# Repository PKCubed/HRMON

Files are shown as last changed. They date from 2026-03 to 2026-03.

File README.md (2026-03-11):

# HRMON
A Stethoscope-shaped Heart Rate Monitor Badge<br>
Created for WWU ENGR355 Winter 2026<br>
Based on the NXP Kinetis KL25 MCU



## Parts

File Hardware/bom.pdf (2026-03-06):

bom

Id Designator | Footprint | Quantity
1 C3,C1,C12,C13 | C_0805_2012Metric_Pad1.18x1.45mm_HandSolder | 4
2 C14,C4,C5,C10,C15,C9,C7,C8 C_0805_2012Metric_Pad1.18x1.45mm_HandSolder | 8
3 J3 | PinHeader_1x08_P2.54mm_Vertical | 1
4 D1,D2,D3 | LED_1206_3216Metric_Pad1.42x1.75mm_HandSolder | 3
5 J9 | PinHeader_1x04_P2.54mm_Vertical | 1
6 D5,D7,D6,D8,D9,D4 | LED_RGB_5050-6 | 6
7 R2,R1,R3 | C_0805_2012Metric_Pad1.18x1.45mm_HandSolder | 3
8 S1,S2,S5,S3,S4 | SW_B3F-1000 | 5
9 R13,R12 | C_0805_2012Metric_Pad1.18x1.45mm_HandSolder | 2
10 R5,R4 | C_0805_2012Metric_Pad1.18x1.45mm_HandSolder | 2
11 C2,C6 | C_0805_2012Metric_Pad1.18x1.45mm_HandSolder | 2
12 U4 | SOIJ8-M_MC_MCH | 1
13 R8,R7 | C_0805_2012Metric_Pad1.18x1.45mm_HandSolder | 2
14 R6 | C_0805_2012Metric_Pad1.18x1.45mm_HandSolder | 1
15 R11,R10 | C_0805_2012Metric_Pad1.18x1.45mm_HandSolder | 2
16 FB1 | L_0603_1608Metric_Pad1.05x0.95mm_HandSolder | 1
17 J1 | PinHeader_2x08_P2.54mm_Vertical | 1
18 R9 | C_0805_2012Metric_Pad1.18x1.45mm_HandSolder | 1
19 J8,J7,J5 | PinHeader_1x02_P2.54mm_Vertical | 3
20 J2 | PinHeader_1x16_P2.54mm_Vertical | 1
21 J4 | PinSocket_2x05_P1.27mm_Vertical | 1
22 SW1 | 09.03290_EAO | 1
23 Q1 | SOT-23_Handsoldering | 1
24 C11 | C_0805_2012Metric_Pad1.18x1.45mm_HandSolder | 1
25 Y1 | XTAL_ABM3-8.000MHZ-D2Y-T | 1
26 U1 | LQFP-80_12x12mm_P0.5mm | 1
27 U5 | DBV5 | 1
28 J6 | PinHeader_2x02_P2.54mm_Vertical | 1
29 U3 | TO-92_Inline | 1

bom

Designation | Supplier and ref Have already?
10uF
0.1uF
Conn_01x08_Pin
LED
Conn_01x04_Pin
APA102
220
B3F-1000
10k
510
1uF
25LC1024-I/SM
4.7k
1k
2Meg
FerriteBead
8x2 Character LCD
1000R
Conn_01x02_Pin
Conn_01x16_Pin
Conn_02x05_Odd_Even
09.03290.01
NPN
1u
ABM3-8.000MHZ-D2Y-T
MKL25Z128VLK4
OPA377AIDBVR
Conn_02x02_Odd_Even
MCP1700x-330xxTO

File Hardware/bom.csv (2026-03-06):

Id | Designator | Footprint | Quantity | Designation | Supplier and ref
1 | C3,C1,C12,C13 | C_0805_2012Metric_Pad1.18x1.45mm_HandSolder | 4 | 10uF
2 | C14,C4,C5,C10,C15,C9,C7,C8 | C_0805_2012Metric_Pad1.18x1.45mm_HandSolder | 8 | 0.1uF
3 | J3 | PinHeader_1x08_P2.54mm_Vertical | 1 | Conn_01x08_Pin
4 | D1,D2,D3 | LED_1206_3216Metric_Pad1.42x1.75mm_HandSolder | 3 | LED
5 | J9 | PinHeader_1x04_P2.54mm_Vertical | 1 | Conn_01x04_Pin
6 | D5,D7,D6,D8,D9,D4 | LED_RGB_5050-6 | 6 | APA102
7 | R2,R1,R3 | C_0805_2012Metric_Pad1.18x1.45mm_HandSolder | 3 | 220
8 | S1,S2,S5,S3,S4 | SW_B3F-1000 | 5 | B3F-1000
9 | R13,R12 | C_0805_2012Metric_Pad1.18x1.45mm_HandSolder | 2 | 10k
10 | R5,R4 | C_0805_2012Metric_Pad1.18x1.45mm_HandSolder | 2 | 510
11 | C2,C6 | C_0805_2012Metric_Pad1.18x1.45mm_HandSolder | 2 | 1uF
12 | U4 | SOIJ8-M_MC_MCH | 1 | 25LC1024-I/SM
13 | R8,R7 | C_0805_2012Metric_Pad1.18x1.45mm_HandSolder | 2 | 4.7k
14 | R6 | C_0805_2012Metric_Pad1.18x1.45mm_HandSolder | 1 | 1k
15 | R11,R10 | C_0805_2012Metric_Pad1.18x1.45mm_HandSolder | 2 | 2Meg
16 | FB1 | L_0603_1608Metric_Pad1.05x0.95mm_HandSolder | 1 | FerriteBead
17 | J1 | PinHeader_2x08_P2.54mm_Vertical | 1 | 8x2 Character LCD
18 | R9 | C_0805_2012Metric_Pad1.18x1.45mm_HandSolder | 1 | 1000R
19 | J8,J7,J5 | PinHeader_1x02_P2.54mm_Vertical | 3 | Conn_01x02_Pin
20 | J2 | PinHeader_1x16_P2.54mm_Vertical | 1 | Conn_01x16_Pin
21 | J4 | PinSocket_2x05_P1.27mm_Vertical | 1 | Conn_02x05_Odd_Even
22 | SW1 | 09.03290_EAO | 1 | 09.03290.01
23 | Q1 | SOT-23_Handsoldering | 1 | NPN
24 | C11 | C_0805_2012Metric_Pad1.18x1.45mm_HandSolder | 1 | 1u
25 | Y1 | XTAL_ABM3-8.000MHZ-D2Y-T | 1 | ABM3-8.000MHZ-D2Y-T
26 | U1 | LQFP-80_12x12mm_P0.5mm | 1 | MKL25Z128VLK4
27 | U5 | DBV5 | 1 | OPA377AIDBVR
28 | J6 | PinHeader_2x02_P2.54mm_Vertical | 1 | Conn_02x02_Odd_Even
29 | U3 | TO-92_Inline | 1 | MCP1700x-330xxTO

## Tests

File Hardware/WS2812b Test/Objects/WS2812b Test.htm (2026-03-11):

# Static Call Graph for image .\Objects\WS2812b Test.axf

#<CALLGRAPH># ARM Linker, 6240002: Last Updated: Sun Jan 18 12:48:08 2026

### Maximum Stack Usage = 68 bytes + Unknown(Functions without stacksize, Cycles, Untraceable Function Pointers)

### Call chain for Maximum Stack Depth:

__rt_entry_main ⇒ main ⇒ Send_Pixel

### Functions with no stack information

- __user_initial_stackheap

### Mutually Recursive functions

- NMI_Handler ⇒ NMI_Handler
- HardFault_Handler ⇒ HardFault_Handler
- SVC_Handler ⇒ SVC_Handler
- PendSV_Handler ⇒ PendSV_Handler
- SysTick_Handler ⇒ SysTick_Handler

### Function Pointers

- ADC0_IRQHandler from startup_mkl25z4.o(.text) referenced from startup_mkl25z4.o(RESET)
- CMP0_IRQHandler from startup_mkl25z4.o(.text) referenced from startup_mkl25z4.o(RESET)
- DAC0_IRQHandler from startup_mkl25z4.o(.text) referenced from startup_mkl25z4.o(RESET)
- DMA0_IRQHandler from startup_mkl25z4.o(.text) referenced from startup_mkl25z4.o(RESET)
- DMA1_IRQHandler from startup_mkl25z4.o(.text) referenced from startup_mkl25z4.o(RESET)
- DMA2_IRQHandler from startup_mkl25z4.o(.text) referenced from startup_mkl25z4.o(RESET)
- DMA3_IRQHandler from startup_mkl25z4.o(.text) referenced from startup_mkl25z4.o(RESET)
- DefaultISR from startup_mkl25z4.o(.text) referenced from startup_mkl25z4.o(.text)
- FTFA_IRQHandler from startup_mkl25z4.o(.text) referenced from startup_mkl25z4.o(RESET)
- HardFault_Handler from startup_mkl25z4.o(.text) referenced from startup_mkl25z4.o(RESET)
- I2C0_IRQHandler from startup_mkl25z4.o(.text) referenced from startup_mkl25z4.o(RESET)
- I2C1_IRQHandler from startup_mkl25z4.o(.text) referenced from startup_mkl25z4.o(RESET)
- LLWU_IRQHandler from startup_mkl25z4.o(.text) referenced from startup_mkl25z4.o(RESET)
- LPTMR0_IRQHandler from startup_mkl25z4.o(.text) referenced from startup_mkl25z4.o(RESET)
- LVD_LVW_IRQHandler from startup_mkl25z4.o(.text) referenced from startup_mkl25z4.o(RESET)
- MCG_IRQHandler from startup_mkl25z4.o(.text) referenced from startup_mkl25z4.o(RESET)
- NMI_Handler from startup_mkl25z4.o(.text) referenced from startup_mkl25z4.o(RESET)
- PIT_IRQHandler from startup_mkl25z4.o(.text) referenced from startup_mkl25z4.o(RESET)
- PORTA_IRQHandler from startup_mkl25z4.o(.text) referenced from startup_mkl25z4.o(RESET)
- PORTD_IRQHandler from startup_mkl25z4.o(.text) referenced from startup_mkl25z4.o(RESET)
- PendSV_Handler from startup_mkl25z4.o(.text) referenced from startup_mkl25z4.o(RESET)
- RTC_IRQHandler from startup_mkl25z4.o(.text) referenced from startup_mkl25z4.o(RESET)
- RTC_Seconds_IRQHandler from startup_mkl25z4.o(.text) referenced from startup_mkl25z4.o(RESET)
- Reserved20_IRQHandler from startup_mkl25z4.o(.text) referenced from startup_mkl25z4.o(RESET)
- Reserved39_IRQHandler from startup_mkl25z4.o(.text) referenced from startup_mkl25z4.o(RESET)
- Reserved45_IRQHandler from startup_mkl25z4.o(.text) referenced from startup_mkl25z4.o(RESET)
- Reset_Handler from startup_mkl25z4.o(.text) referenced from startup_mkl25z4.o(RESET)
- SPI0_IRQHandler from startup_mkl25z4.o(.text) referenced from startup_mkl25z4.o(RESET)
- SPI1_IRQHandler from startup_mkl25z4.o(.text) referenced from startup_mkl25z4.o(RESET)
- SVC_Handler from startup_mkl25z4.o(.text) referenced from startup_mkl25z4.o(RESET)
- SysTick_Handler from startup_mkl25z4.o(.text) referenced from startup_mkl25z4.o(RESET)
- SystemInit from system_mkl25z4.o(.text.SystemInit) referenced from startup_mkl25z4.o(.text)
- TPM0_IRQHandler from startup_mkl25z4.o(.text) referenced from startup_mkl25z4.o(RESET)
- TPM1_IRQHandler from startup_mkl25z4.o(.text) referenced from startup_mkl25z4.o(RESET)
- TPM2_IRQHandler from startup_mkl25z4.o(.text) referenced from startup_mkl25z4.o(RESET)
- TSI0_IRQHandler from startup_mkl25z4.o(.text) referenced from startup_mkl25z4.o(RESET)
- UART0_IRQHandler from startup_mkl25z4.o(.text) referenced from startup_mkl25z4.o(RESET)
- UART1_IRQHandler from startup_mkl25z4.o(.text) referenced from startup_mkl25z4.o(RESET)
- UART2_IRQHandler from startup_mkl25z4.o(.text) referenced from startup_mkl25z4.o(RESET)
- USB0_IRQHandler from startup_mkl25z4.o(.text) referenced from startup_mkl25z4.o(RESET)
- __main from __main.o(!!!main) referenced from startup_mkl25z4.o(.text)

### Global Symbols

__main (Thumb, 8 bytes, Stack size 0 bytes, __main.o(!!!main))

[Calls]

- >> __scatterload
- >> __rt_entry

[Address Reference Count : 1]

- startup_mkl25z4.o(.text)

__scatterload (Thumb, 0 bytes, Stack size unknown bytes, __scatter.o(!!!scatter))

[Called By]

- >> __main

__scatterload_rt2 (Thumb, 74 bytes, Stack size unknown bytes, __scatter.o(!!!scatter), UNUSED)

[Calls]

- >> __rt_entry

__scatterload_rt2_thumb_only (Thumb, 0 bytes, Stack size unknown bytes, __scatter.o(!!!scatter), UNUSED)

__scatterload_loop (Thumb, 0 bytes, Stack size unknown bytes, __scatter.o(!!!scatter), UNUSED)

__scatterload_null (Thumb, 2 bytes, Stack size unknown bytes, __scatter.o(!!handler_null), UNUSED)

__scatterload_zeroinit (Thumb, 28 bytes, Stack size unknown bytes, __scatter_zi.o(!!handler_zi), UNUSED)

__rt_lib_init (Thumb, 0 bytes, Stack size unknown bytes, libinit.o(.ARM.Collect$$libinit$$00000000))

[Called By]

- >> __rt_entry_li

__rt_lib_init_alloca_1 (Thumb, 0 bytes, Stack size unknown bytes, libinit2.o(.ARM.Collect$$libinit$$00000030))

__rt_lib_init_argv_1 (Thumb, 0 bytes, Stack size unknown bytes, libinit2.o(.ARM.Collect$$libinit$$0000002E))

__rt_lib_init_atexit_1 (Thumb, 0 bytes, Stack size unknown bytes, libinit2.o(.ARM.Collect$$libinit$$0000001D))

__rt_lib_init_clock_1 (Thumb, 0 bytes, Stack size unknown bytes, libinit2.o(.ARM.Collect$$libinit$$00000023))

__rt_lib_init_cpp_1 (Thumb, 0 bytes, Stack size unknown bytes, libinit2.o(.ARM.Collect$$libinit$$00000034))

__rt_lib_init_exceptions_1 (Thumb, 0 bytes, Stack size unknown bytes, libinit2.o(.ARM.Collect$$libinit$$00000032))

__rt_lib_init_fp_1 (Thumb, 0 bytes, Stack size unknown bytes, libinit2.o(.ARM.Collect$$libinit$$00000002))

__rt_lib_init_fp_trap_1 (Thumb, 0 bytes, Stack size unknown bytes, libinit2.o(.ARM.Collect$$libinit$$00000021))

__rt_lib_init_getenv_1 (Thumb, 0 bytes, Stack size unknown bytes, libinit2.o(.ARM.Collect$$libinit$$00000025))

__rt_lib_init_heap_1 (Thumb, 0 bytes, Stack size unknown bytes, libinit2.o(.ARM.Collect$$libinit$$0000000C))

__rt_lib_init_lc_collate_1 (Thumb, 0 bytes, Stack size unknown bytes, libinit2.o(.ARM.Collect$$libinit$$00000013))

__rt_lib_init_lc_ctype_1 (Thumb, 0 bytes, Stack size unknown bytes, libinit2.o(.ARM.Collect$$libinit$$00000015))

__rt_lib_init_lc_monetary_1 (Thumb, 0 bytes, Stack size unknown bytes, libinit2.o(.ARM.Collect$$libinit$$00000017))

__rt_lib_init_lc_numeric_1 (Thumb, 0 bytes, Stack size unknown bytes, libinit2.o(.ARM.Collect$$libinit$$00000019))

__rt_lib_init_lc_time_1 (Thumb, 0 bytes, Stack size unknown bytes, libinit2.o(.ARM.Collect$$libinit$$0000001B))

__rt_lib_init_preinit_1 (Thumb, 0 bytes, Stack size unknown bytes, libinit2.o(.ARM.Collect$$libinit$$00000006))

__rt_lib_init_rand_1 (Thumb, 0 bytes, Stack size unknown bytes, libinit2.o(.ARM.Collect$$libinit$$00000010))

__rt_lib_init_relocate_pie_1 (Thumb, 0 bytes, Stack size unknown bytes, libinit2.o(.ARM.Collect$$libinit$$00000004))

__rt_lib_init_return (Thumb, 0 bytes, Stack size unknown bytes, libinit2.o(.ARM.Collect$$libinit$$00000035))

__rt_lib_init_signal_1 (Thumb, 0 bytes, Stack size unknown bytes, libinit2.o(.ARM.Collect$$libinit$$0000001F))

__rt_lib_init_stdio_1 (Thumb, 0 bytes, Stack size unknown bytes, libinit2.o(.ARM.Collect$$libinit$$00000027))

__rt_lib_init_user_alloc_1 (Thumb, 0 bytes, Stack size unknown bytes, libinit2.o(.ARM.Collect$$libinit$$0000000E))

__rt_lib_shutdown (Thumb, 0 bytes, Stack size unknown bytes, libshutdown.o(.ARM.Collect$$libshutdown$$00000000))

[Called By]

- >> __rt_exit_ls

__rt_lib_shutdown_cpp_1 (Thumb, 0 bytes, Stack size unknown bytes, libshutdown2.o(.ARM.Collect$$libshutdown$$00000002))

__rt_lib_shutdown_fp_trap_1 (Thumb, 0 bytes, Stack size unknown bytes, libshutdown2.o(.ARM.Collect$$libshutdown$$00000007))

__rt_lib_shutdown_heap_1 (Thumb, 0 bytes, Stack size unknown bytes, libshutdown2.o(.ARM.Collect$$libshutdown$$0000000F))

__rt_lib_shutdown_return (Thumb, 0 bytes, Stack size unknown bytes, libshutdown2.o(.ARM.Collect$$libshutdown$$00000010))

__rt_lib_shutdown_signal_1 (Thumb, 0 bytes, Stack size unknown bytes, libshutdown2.o(.ARM.Collect$$libshutdown$$0000000A))

__rt_lib_shutdown_stdio_1 (Thumb, 0 bytes, Stack size unknown bytes, libshutdown2.o(.ARM.Collect$$libshutdown$$00000004))

__rt_lib_shutdown_user_alloc_1 (Thumb, 0 bytes, Stack size unknown bytes, libshutdown2.o(.ARM.Collect$$libshutdown$$0000000C))

__rt_entry (Thumb, 0 bytes, Stack size unknown bytes, __rtentry.o(.ARM.Collect$$rtentry$$00000000))

[Called By]

- >> __scatterload_rt2
- >> __main

__rt_entry_presh_1 (Thumb, 0 bytes, Stack size unknown bytes, __rtentry2.o(.ARM.Collect$$rtentry$$00000002))

__rt_entry_sh (Thumb, 0 bytes, Stack size unknown bytes, __rtentry4.o(.ARM.Collect$$rtentry$$00000004))

[Stack]

- Max Depth = 8 + Unknown Stack Size
- Call Chain = __rt_entry_sh ⇒ __user_setup_stackheap

[Calls]

- >> __user_setup_stackheap

__rt_entry_li (Thumb, 0 bytes, Stack size unknown bytes, __rtentry2.o(.ARM.Collect$$rtentry$$0000000A))

[Calls]

- >> __rt_lib_init

__rt_entry_postsh_1 (Thumb, 0 bytes, Stack size unknown bytes, __rtentry2.o(.ARM.Collect$$rtentry$$00000009))

__rt_entry_main (Thumb, 0 bytes, Stack size unknown bytes, __rtentry2.o(.ARM.Collect$$rtentry$$0000000D))

[Stack]

- Max Depth = 68 + Unknown Stack Size
- Call Chain = __rt_entry_main ⇒ main ⇒ Send_Pixel

[Calls]

- >> exit
- >> main

__rt_entry_postli_1 (Thumb, 0 bytes, Stack size unknown bytes, __rtentry2.o(.ARM.Collect$$rtentry$$0000000C))

__rt_exit (Thumb, 0 bytes, Stack size unknown bytes, rtexit.o(.ARM.Collect$$rtexit$$00000000))

[Called By]

- >> exit

__rt_exit_ls (Thumb, 0 bytes, Stack size unknown bytes, rtexit2.o(.ARM.Collect$$rtexit$$00000003))

[Calls]

- >> __rt_lib_shutdown

__rt_exit_prels_1 (Thumb, 0 bytes, Stack size unknown bytes, rtexit2.o(.ARM.Collect$$rtexit$$00000002))

__rt_exit_exit (Thumb, 0 bytes, Stack size unknown bytes, rtexit2.o(.ARM.Collect$$rtexit$$00000004))

[Calls]

- >> _sys_exit

Reset_Handler (Thumb, 12 bytes, Stack size 0 bytes, startup_mkl25z4.o(.text))
[Address Reference Count : 1]

- startup_mkl25z4.o(RESET)

NMI_Handler (Thumb, 2 bytes, Stack size 0 bytes, startup_mkl25z4.o(.text))

[Calls]

- >> NMI_Handler

[Called By]

- >> NMI_Handler

[Address Reference Count : 1]

- startup_mkl25z4.o(RESET)

HardFault_Handler (Thumb, 2 bytes, Stack size 0 bytes, startup_mkl25z4.o(.text))

[Calls]

- >> HardFault_Handler

[Called By]

- >> HardFault_Handler

[Address Reference Count : 1]

- startup_mkl25z4.o(RESET)

SVC_Handler (Thumb, 2 bytes, Stack size 0 bytes, startup_mkl25z4.o(.text))

[Calls]

- >> SVC_Handler

[Called By]

- >> SVC_Handler

[Address Reference Count : 1]

- startup_mkl25z4.o(RESET)

PendSV_Handler (Thumb, 2 bytes, Stack size 0 bytes, startup_mkl25z4.o(.text))

[Calls]

- >> PendSV_Handler

[Called By]

- >> PendSV_Handler

[Address Reference Count : 1]

- startup_mkl25z4.o(RESET)

SysTick_Handler (Thumb, 2 bytes, Stack size 0 bytes, startup_mkl25z4.o(.text))

[Calls]

- >> SysTick_Handler

[Called By]

- >> SysTick_Handler

[Address Reference Count : 1]

- startup_mkl25z4.o(RESET)

ADC0_IRQHandler (Thumb, 0 bytes, Stack size 0 bytes, startup_mkl25z4.o(.text))
[Address Reference Count : 1]

- startup_mkl25z4.o(RESET)

CMP0_IRQHandler (Thumb, 0 bytes, Stack size 0 bytes, startup_mkl25z4.o(.text))
[Address Reference Count : 1]

- startup_mkl25z4.o(RESET)

DAC0_IRQHandler (Thumb, 0 bytes, Stack size 0 bytes, startup_mkl25z4.o(.text))
[Address Reference Count : 1]

- startup_mkl25z4.o(RESET)

DMA0_IRQHandler (Thumb, 0 bytes, Stack size 0 bytes, startup_mkl25z4.o(.text))
[Address Reference Count : 1]

- startup_mkl25z4.o(RESET)

DMA1_IRQHandler (Thumb, 0 bytes, Stack size 0 bytes, startup_mkl25z4.o(.text))
[Address Reference Count : 1]

- startup_mkl25z4.o(RESET)

DMA2_IRQHandler (Thumb, 0 bytes, Stack size 0 bytes, startup_mkl25z4.o(.text))
[Address Reference Count : 1]

- startup_mkl25z4.o(RESET)

DMA3_IRQHandler (Thumb, 0 bytes, Stack size 0 bytes, startup_mkl25z4.o(.text))
[Address Reference Count : 1]

- startup_mkl25z4.o(RESET)

DefaultISR (Thumb, 0 bytes, Stack size 0 bytes, startup_mkl25z4.o(.text))
[Address Reference Count : 1]

- startup_mkl25z4.o(.text)

FTFA_IRQHandler (Thumb, 0 bytes, Stack size 0 bytes, startup_mkl25z4.o(.text))
[Address Reference Count : 1]

- startup_mkl25z4.o(RESET)

I2C0_IRQHandler (Thumb, 0 bytes, Stack size 0 bytes, startup_mkl25z4.o(.text))
[Address Reference Count : 1]

- startup_mkl25z4.o(RESET)

I2C1_IRQHandler (Thumb, 0 bytes, Stack size 0 bytes, startup_mkl25z4.o(.text))
[Address Reference Count : 1]

- startup_mkl25z4.o(RESET)

LLWU_IRQHandler (Thumb, 0 bytes, Stack size 0 bytes, startup_mkl25z4.o(.text))
[Address Reference Count : 1]

- startup_mkl25z4.o(RESET)

LPTMR0_IRQHandler (Thumb, 0 bytes, Stack size 0 bytes, startup_mkl25z4.o(.text))
[Address Reference Count : 1]

- startup_mkl25z4.o(RESET)

LVD_LVW_IRQHandler (Thumb, 0 bytes, Stack size 0 bytes, startup_mkl25z4.o(.text))
[Address Reference Count : 1]

- startup_mkl25z4.o(RESET)

MCG_IRQHandler (Thumb, 0 bytes, Stack size 0 bytes, startup_mkl25z4.o(.text))
[Address Reference Count : 1]

- startup_mkl25z4.o(RESET)

PIT_IRQHandler (Thumb, 0 bytes, Stack size 0 bytes, startup_mkl25z4.o(.text))
[Address Reference Count : 1]

- startup_mkl25z4.o(RESET)

PORTA_IRQHandler (Thumb, 0 bytes, Stack size 0 bytes, startup_mkl25z4.o(.text))
[Address Reference Count : 1]

- startup_mkl25z4.o(RESET)

PORTD_IRQHandler (Thumb, 0 bytes, Stack size 0 bytes, startup_mkl25z4.o(.text))
[Address Reference Count : 1]

- startup_mkl25z4.o(RESET)

RTC_IRQHandler (Thumb, 0 bytes, Stack size 0 bytes, startup_mkl25z4.o(.text))
[Address Reference Count : 1]

- startup_mkl25z4.o(RESET)

RTC_Seconds_IRQHandler (Thumb, 0 bytes, Stack size 0 bytes, startup_mkl25z4.o(.text))
[Address Reference Count : 1]

- startup_mkl25z4.o(RESET)

Reserved20_IRQHandler (Thumb, 0 bytes, Stack size 0 bytes, startup_mkl25z4.o(.text))
[Address Reference Count : 1]

- startup_mkl25z4.o(RESET)

Reserved39_IRQHandler (Thumb, 0 bytes, Stack size 0 bytes, startup_mkl25z4.o(.text))
[Address Reference Count : 1]

- startup_mkl25z4.o(RESET)

Reserved45_IRQHandler (Thumb, 0 bytes, Stack size 0 bytes, startup_mkl25z4.o(.text))
[Address Reference Count : 1]

- startup_mkl25z4.o(RESET)

SPI0_IRQHandler (Thumb, 0 bytes, Stack size 0 bytes, startup_mkl25z4.o(.text))
[Address Reference Count : 1]

- startup_mkl25z4.o(RESET)

SPI1_IRQHandler (Thumb, 0 bytes, Stack size 0 bytes, startup_mkl25z4.o(.text))
[Address Reference Count : 1]

- startup_mkl25z4.o(RESET)

TPM0_IRQHandler (Thumb, 0 bytes, Stack size 0 bytes, startup_mkl25z4.o(.text))
[Address Reference Count : 1]

- startup_mkl25z4.o(RESET)

TPM1_IRQHandler (Thumb, 0 bytes, Stack size 0 bytes, startup_mkl25z4.o(.text))
[Address Reference Count : 1]

- startup_mkl25z4.o(RESET)

TPM2_IRQHandler (Thumb, 0 bytes, Stack size 0 bytes, startup_mkl25z4.o(.text))
[Address Reference Count : 1]

- startup_mkl25z4.o(RESET)

TSI0_IRQHandler (Thumb, 0 bytes, Stack size 0 bytes, startup_mkl25z4.o(.text))
[Address Reference Count : 1]

- startup_mkl25z4.o(RESET)

UART0_IRQHandler (Thumb, 0 bytes, Stack size 0 bytes, startup_mkl25z4.o(.text))
[Address Reference Count : 1]

- startup_mkl25z4.o(RESET)

UART1_IRQHandler (Thumb, 0 bytes, Stack size 0 bytes, startup_mkl25z4.o(.text))
[Address Reference Count : 1]

- startup_mkl25z4.o(RESET)

UART2_IRQHandler (Thumb, 0 bytes, Stack size 0 bytes, startup_mkl25z4.o(.text))
[Address Reference Count : 1]

- startup_mkl25z4.o(RESET)

USB0_IRQHandler (Thumb, 0 bytes, Stack size 0 bytes, startup_mkl25z4.o(.text))
[Address Reference Count : 1]

- startup_mkl25z4.o(RESET)

__user_initial_stackheap (Thumb, 0 bytes, Stack size unknown bytes, startup_mkl25z4.o(.text))

[Called By]

- >> __user_setup_stackheap

__use_two_region_memory (Thumb, 2 bytes, Stack size 0 bytes, heapauxi.o(.text), UNUSED)

__rt_heap_escrow$2region (Thumb, 2 bytes, Stack size 0 bytes, heapauxi.o(.text), UNUSED)

__rt_heap_expand$2region (Thumb, 2 bytes, Stack size 0 bytes, heapauxi.o(.text), UNUSED)

__user_setup_stackheap (Thumb, 62 bytes, Stack size 8 bytes, sys_stackheap_outer.o(.text))

[Stack]

- Max Depth = 8 + Unknown Stack Size
- Call Chain = __user_setup_stackheap

[Calls]

- >> __user_perproc_libspace
- >> __user_initial_stackheap

[Called By]

- >> __rt_entry_sh

exit (Thumb, 16 bytes, Stack size 8 bytes, exit.o(.text))

[Stack]

- Max Depth = 8 + Unknown Stack Size
- Call Chain = exit

[Calls]

- >> __rt_exit
- >> _call_atexit_fns (Weak Reference)

[Called By]

- >> __rt_entry_main

__user_libspace (Thumb, 8 bytes, Stack size 0 bytes, libspace.o(.text), UNUSED)

__user_perproc_libspace (Thumb, 0 bytes, Stack size 0 bytes, libspace.o(.text))

[Called By]

- >> __user_setup_stackheap

__user_perthread_libspace (Thumb, 0 bytes, Stack size 0 bytes, libspace.o(.text), UNUSED)

_sys_exit (Thumb, 8 bytes, Stack size 0 bytes, sys_exit.o(.text))

[Called By]

- >> __rt_exit_exit

__I$use$semihosting (Thumb, 0 bytes, Stack size 0 bytes, use_no_semi.o(.text), UNUSED)

__use_no_semihosting_swi (Thumb, 2 bytes, Stack size 0 bytes, use_no_semi.o(.text), UNUSED)

Delay (Thumb, 26 bytes, Stack size 4 bytes, main.o(.text.Delay))

[Stack]

- Max Depth = 4
- Call Chain = Delay

[Called By]

- >> main

__semihosting_library_function (Thumb, 0 bytes, Stack size 4 bytes, indicate_semi.o(.text), UNUSED)

Init_GPIO (Thumb, 36 bytes, Stack size 0 bytes, main.o(.text.Init_GPIO))

[Called By]

- >> main

Send_Pixel (Thumb, 228 bytes, Stack size 44 bytes, main.o(.text.Send_Pixel))

[Stack]

- Max Depth = 44
- Call Chain = Send_Pixel

[Called By]

- >> main

SystemInit (Thumb, 8 bytes, Stack size 0 bytes, system_mkl25z4.o(.text.SystemInit))
[Address Reference Count : 1]

- startup_mkl25z4.o(.text)

main (Thumb, 92 bytes, Stack size 24 bytes, main.o(.text.main))

[Stack]

- Max Depth = 68
- Call Chain = main ⇒ Send_Pixel

[Calls]

- >> Send_Pixel
- >> Init_GPIO
- >> Delay

[Called By]

- >> __rt_entry_main

### Local Symbols

### Undefined Global Symbols

_call_atexit_fns (ARM, 0 bytes, Stack size 0 bytes, UNDEFINED)

[Called By]

- >> exit

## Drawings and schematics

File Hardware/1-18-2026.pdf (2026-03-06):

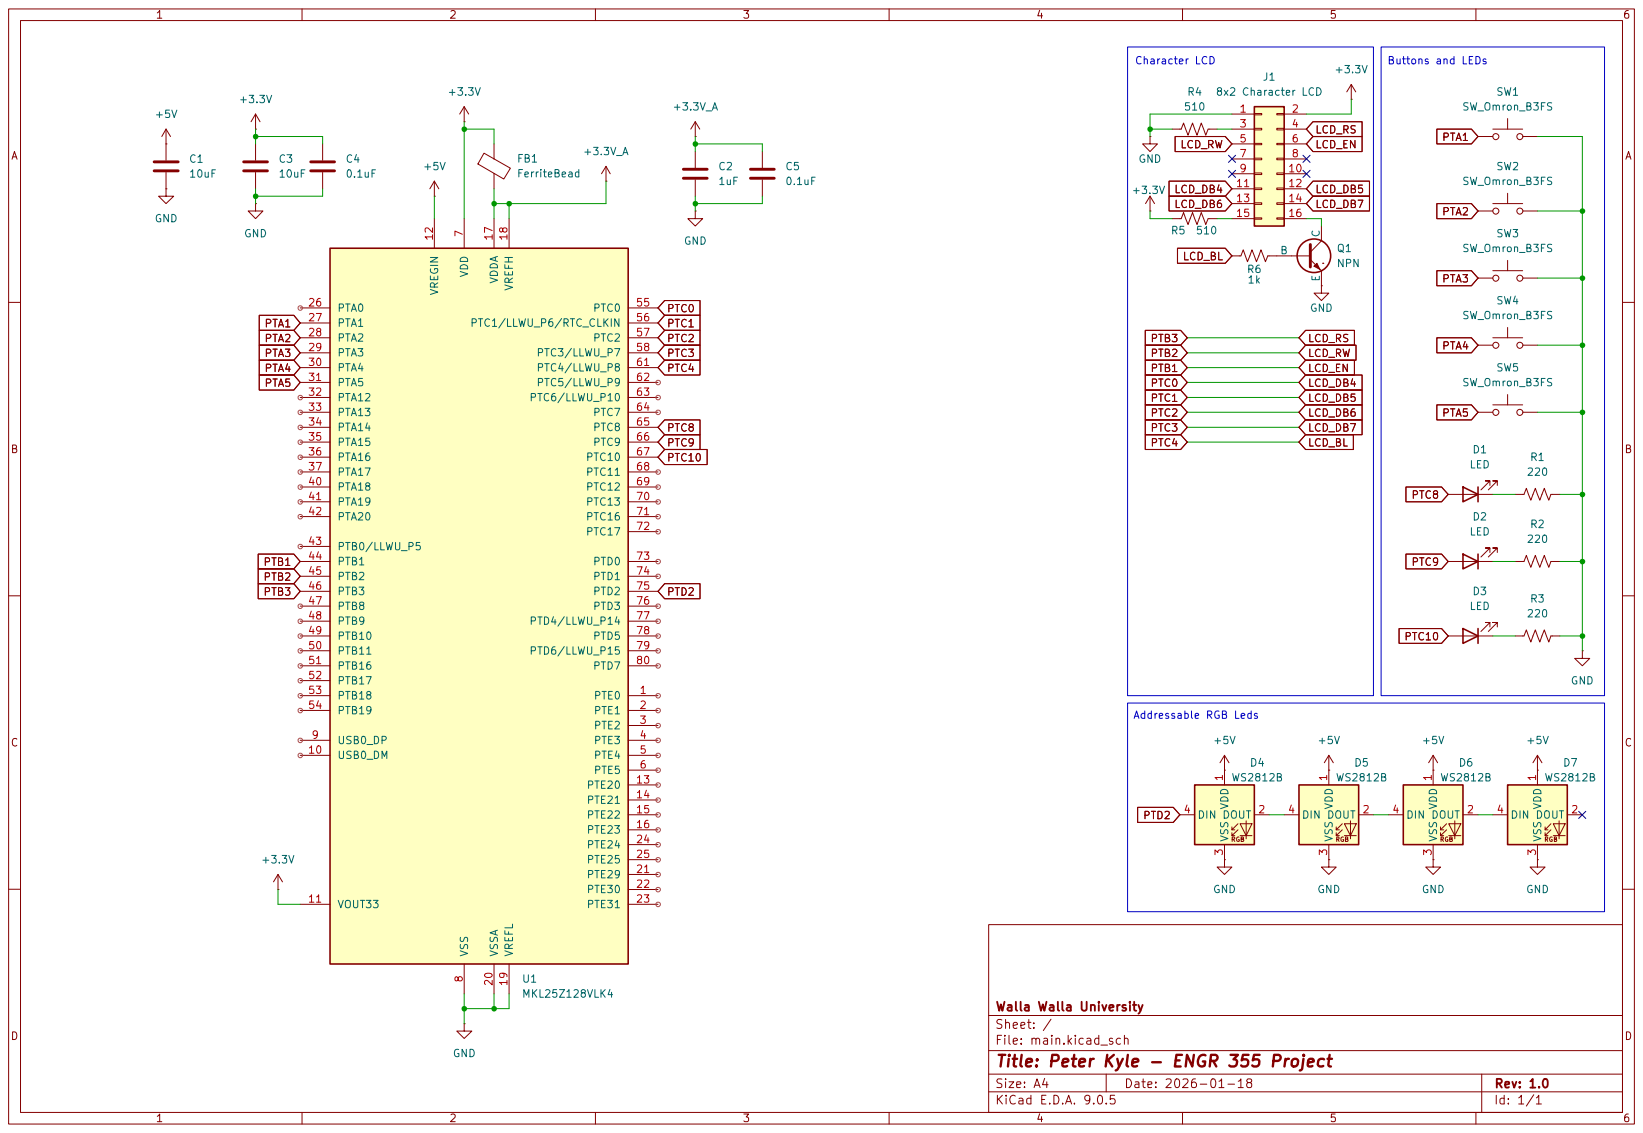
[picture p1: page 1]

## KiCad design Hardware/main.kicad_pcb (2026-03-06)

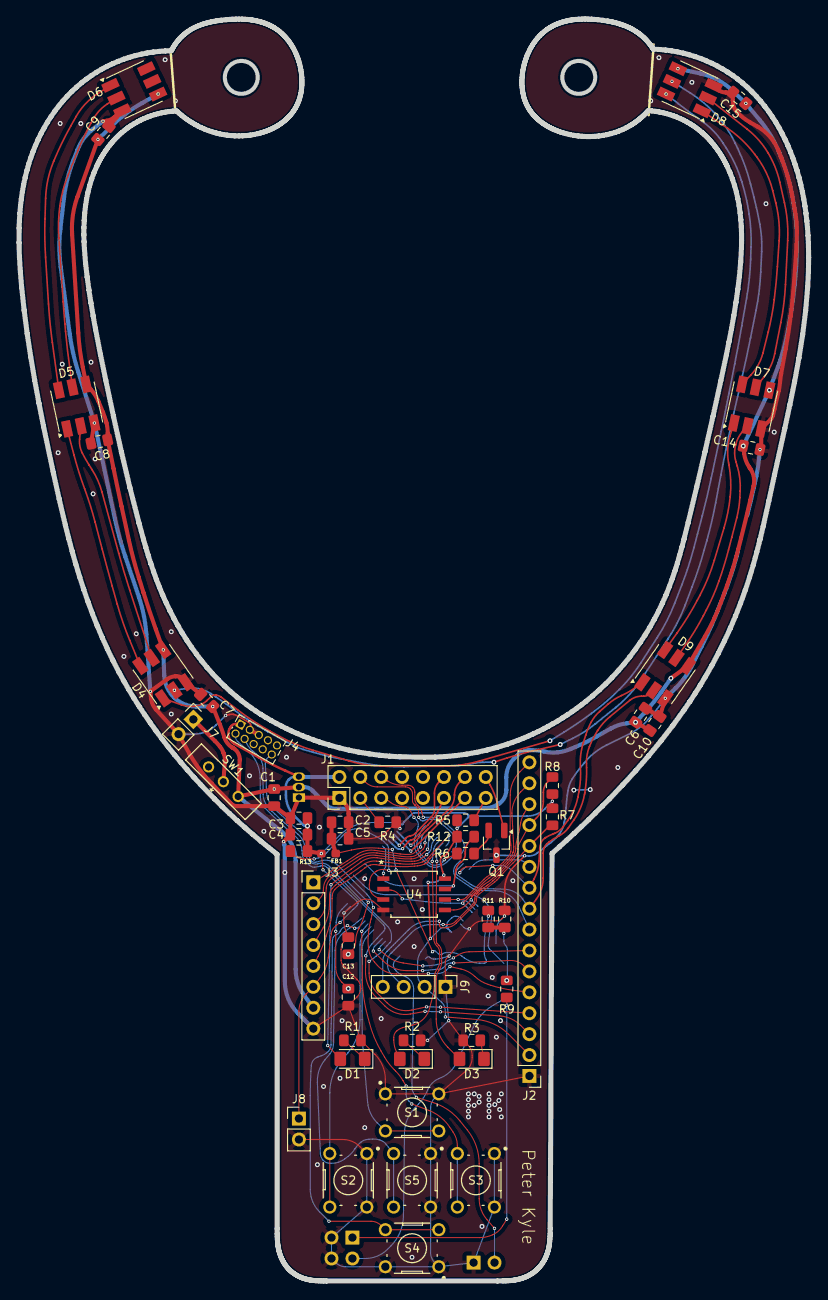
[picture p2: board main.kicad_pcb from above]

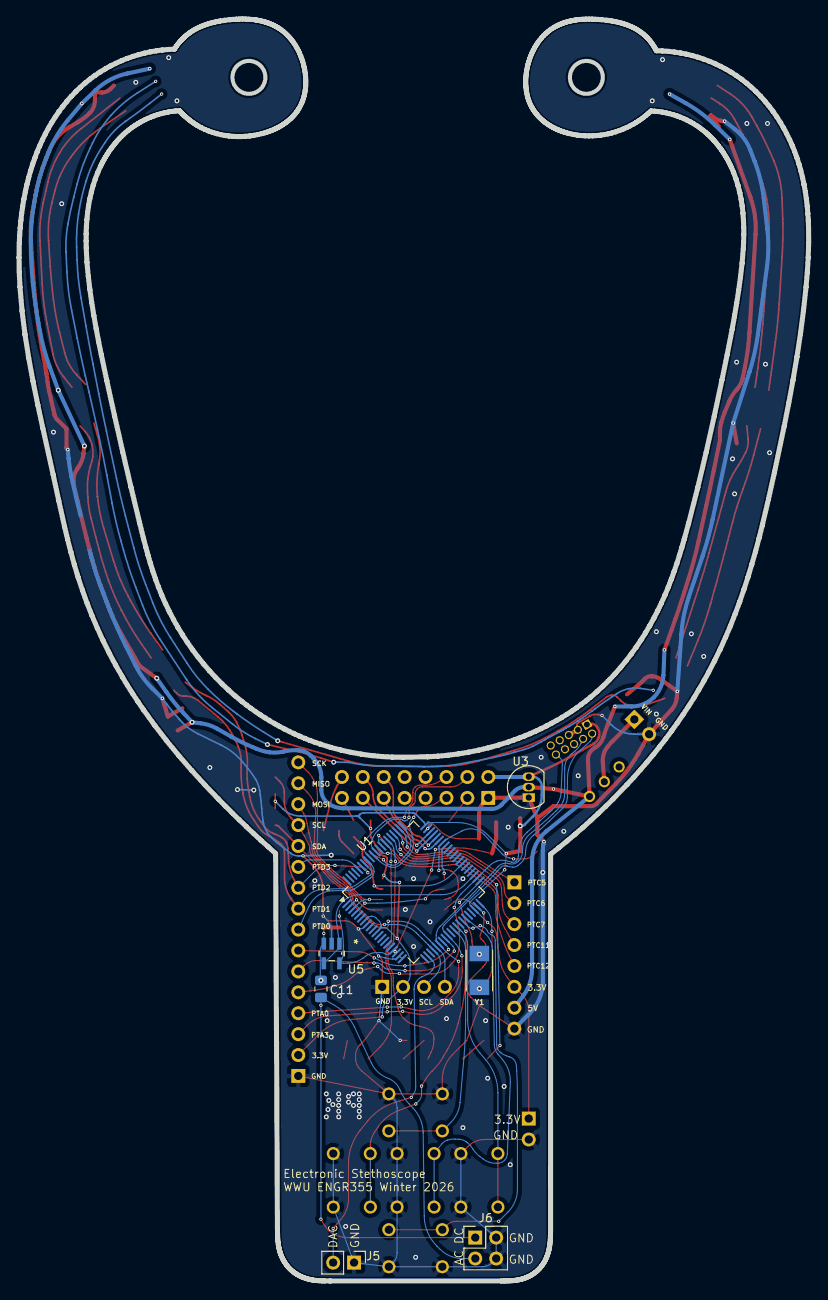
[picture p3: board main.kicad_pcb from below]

Board: 2 copper layers, 95.9 x 153.3 mm, 59 parts (7 on the bottom side), 67 nets.

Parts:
C1, C3, C12, C13: 10uF; C_0805_2012Metric_Pad1.18x1.45mm_HandSolder
C2, C6: 1uF; C_0805_2012Metric_Pad1.18x1.45mm_HandSolder
C4, C5, C7, C8, C9, C10, C14, C15: 0.1uF; C_0805_2012Metric_Pad1.18x1.45mm_HandSolder
C11: 1u; C_0805_2012Metric_Pad1.18x1.45mm_HandSolder
D1, D2, D3: LED; LED_1206_3216Metric_Pad1.42x1.75mm_HandSolder
D4, D5, D6, D7, D8, D9: APA102; LED_RGB_5050-6
FB1: FerriteBead; L_0603_1608Metric_Pad1.05x0.95mm_HandSolder
J1: 8x2 Character LCD; PinHeader_2x08_P2.54mm_Vertical
J2: Conn_01x16_Pin; PinHeader_1x16_P2.54mm_Vertical
J3: Conn_01x08_Pin; PinHeader_1x08_P2.54mm_Vertical
J4: Conn_02x05_Odd_Even; PinSocket_2x05_P1.27mm_Vertical
J5, J7, J8: Conn_01x02_Pin; PinHeader_1x02_P2.54mm_Vertical
J6: Conn_02x02_Odd_Even; PinHeader_2x02_P2.54mm_Vertical
J9: Conn_01x04_Pin; PinHeader_1x04_P2.54mm_Vertical
Q1: NPN; SOT-23_Handsoldering
R1, R2, R3: 220; C_0805_2012Metric_Pad1.18x1.45mm_HandSolder
R4, R5: 510; C_0805_2012Metric_Pad1.18x1.45mm_HandSolder
R6: 1k; C_0805_2012Metric_Pad1.18x1.45mm_HandSolder
R7, R8: 4.7k; C_0805_2012Metric_Pad1.18x1.45mm_HandSolder
R9: 1000R; C_0805_2012Metric_Pad1.18x1.45mm_HandSolder
R10, R11: 2Meg; C_0805_2012Metric_Pad1.18x1.45mm_HandSolder
R12, R13: 10k; C_0805_2012Metric_Pad1.18x1.45mm_HandSolder
S1, S2, S3, S4, S5: B3F-1000; SW_B3F-1000
SW1: 09.03290.01; 09.03290_EAO
U1: MKL25Z128VLK4; LQFP-80_12x12mm_P0.5mm
U3: MCP1700x-330xxTO; TO-92_Inline
U4: 25LC1024-I/SM; SOIJ8-M_MC_MCH
U5: OPA377AIDBVR; DBV5
Y1: ABM3-8.000MHZ-D2Y-T; XTAL_ABM3-8.000MHZ-D2Y-T

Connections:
+3.3V: C3.1, C4.1, FB1.1, J1.2, J2.2, J3.6, J4.1, J8.1, J9.2, R5.1, R7.2, R8.1, R12.2, R13.2, U1.7 (VDD), U1.11 (VOUT33), U1.38 (VDD), U1.60 (VDD), U3.3 (VO), U4.8 (VCC)
+3.3V_A: C2.1, C5.1, FB1.2, R11.1, U1.17 (VDDA), U1.18 (VREFH), U5.5 (V+)
+5V: C1.1, C6.1, C7.1, C8.1, C9.1, C10.1, C14.1, C15.1, D4.4 (VCC), D5.4 (VCC), D6.4 (VCC), D7.4 (VCC), D8.4 (VCC), D9.4 (VCC), J3.7, SW1.2, U3.2 (VI)
EEPROM_CS: U1.53 (PTB18), U4.1 (*CS)
EEPROM_HOLD: R12.1, U1.47 (PTB8), U4.7 (*HOLD)
EEPROM_SCK: J2.16, U1.3 (PTE2), U4.6 (SCK)
EEPROM_SI: J2.14, U1.2 (PTE1), U4.5 (SI)
EEPROM_SO: J2.15, U1.4 (PTE3), U4.2 (SO)
EEPROM_WP: R13.1, U1.54 (PTB19), U4.3 (*WP)
EXTAL0: C12.1, U1.40 (PTA18), Y1.1
GND: C1.2, C2.2, C3.2, C4.2, C5.2, C6.2, C7.2, C8.2, C9.2, C10.2, C12.2, C13.2, C14.2, C15.2, D4.3 (GND), D5.3 (GND), D6.3 (GND), D7.3 (GND), D8.3 (GND), D9.3 (GND), J1.1, J2.1, J3.8, J4.3, J4.5, J5.1, J6.2, J6.4, J7.2, J8.2, J9.1, Q1.3 (E), R1.2, R2.2, R3.2, R4.1, R10.2, S1.1, S1.2, S2.1, S2.2, S3.1, S3.2, S4.1, S4.2, S5.1, S5.2, U1.8 (VSS), U1.19 (VREFL), U1.20 (VSSA), U1.39 (VSS), U1.59 (VSS), U3.1 (GND), U4.4 (VSS), U5.2 (V-)
I2C_SCL: J2.13, J9.3, R8.2, U1.24 (PTE24)
I2C_SDA: J2.12, J9.4, R7.1, U1.25 (PTE25)
LCD_BL: R6.1, U1.61 (PTC4/LLWU_P8)
LCD_DB4: J1.11, U1.55 (PTC0)
LCD_DB5: J1.12, U1.56 (PTC1/LLWU_P6/RTC_CLKIN)
LCD_DB6: J1.13, U1.57 (PTC2)
LCD_DB7: J1.14, U1.58 (PTC3/LLWU_P7)
LCD_EN: J1.6, U1.72 (PTC17)
LCD_RS: J1.4, U1.70 (PTC13)
LCD_RW: J1.5, U1.71 (PTC16)
unnamed: D1.1 (K), R1.1
unnamed: D2.1 (K), R2.1
unnamed: D3.1 (K), R3.1
unnamed: D4.2 (CI), D8.5 (CO)
unnamed: D4.5 (CO), D5.2 (CI)
unnamed: D4.1 (DI), D8.6 (DO)
unnamed: D4.6 (DO), D5.1 (DI)
unnamed: D5.5 (CO), D6.2 (CI)
unnamed: D5.6 (DO), D6.1 (DI)
unnamed: D7.2 (CI), D9.5 (CO)
unnamed: D7.5 (CO), D8.2 (CI)
unnamed: D7.1 (DI), D9.6 (DO)
unnamed: D7.6 (DO), D8.1 (DI)
unnamed: J1.3, R4.2
unnamed: J1.15, R5.2
unnamed: J1.16, Q1.1 (C)
unnamed: J6.1, R9.1
unnamed: C11.2, J6.3
unnamed: J7.1, SW1.1
unnamed: Q1.2 (B), R6.2
unnamed: C11.1, R9.2, R10.1, R11.2, U5.3 (IN+)
Opamp_Out: U1.43 (PTB0/LLWU_P5), U5.1 (OUT), U5.4 (IN-)
PTA0: J2.4, J4.4, U1.26 (PTA0)
PTA1: J2.7, U1.27 (PTA1)
PTA2: J2.6, U1.28 (PTA2)
PTA3: J2.3, J4.2, U1.29 (PTA3)
PTA5: S1.3, S1.4, U1.31 (PTA5)
PTA12: S2.3, S2.4, U1.32 (PTA12)
PTA13: S3.3, S3.4, U1.33 (PTA13)
PTA14: S4.3, S4.4, U1.34 (PTA14)
PTA15: S5.3, S5.4, U1.35 (PTA15)
PTA20: J2.5, J4.10, U1.42 (PTA20)
PTC5: J3.1, U1.62 (PTC5/LLWU_P9)
PTC6: J3.2, U1.63 (PTC6/LLWU_P10)
PTC7: J3.3, U1.64 (PTC7)
PTC8: D1.2 (A), U1.65 (PTC8)
PTC9: D2.2 (A), U1.66 (PTC9)
PTC10: D3.2 (A), U1.67 (PTC10)
PTC11: J3.4, U1.68 (PTC11)
PTC12: J3.5, U1.69 (PTC12)
PTD0: J2.8, U1.73 (PTD0)
PTD1: D9.2 (CI), J2.9, U1.74 (PTD1)
PTD2: D9.1 (DI), J2.10, U1.75 (PTD2)
PTD3: J2.11, U1.76 (PTD3)
PTE30: J5.2, U1.22 (PTE30)
XTAL0: C13.1, U1.41 (PTA19), Y1.2

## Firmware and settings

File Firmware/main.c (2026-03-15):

/*
Peter Kyle

ENGR355 Embedded Systems - Winter 2026
Final Project

Heart Rate Monitor

*/
# include <MKL25Z4.h>
# include <string.h>
# include <stdbool.h>

#define MASK(x) (1UL << (x))

// Pin Definitions
#define LCD_EN 17 // PTC17 LCD Enable (Clock)
#define LCD_RW 16 // PTC16 LCD Read/Write
#define LCD_RS 13 // PTC13 LCD Register Select

// LCD Data pins are PTC0-PTC3

#define LCD_BL 4 // PTC4 Backlight


// Buttons
#define BUTTON_UP 5 // PTA5
#define BUTTON_LEFT 12 // PTA12
#define BUTTON_RIGHT 13 // PTA13
#define BUTTON_DOWN 14 // PTA14
#define BUTTON_CENTER 15 // PTA15

#define DEBOUNCE_DURATION 2000000ULL // Clock Cycles

uint64_t button_up_timer = 0;
uint64_t button_left_timer = 0;
uint64_t button_right_timer = 0;
uint64_t button_down_timer = 0;
uint64_t button_center_timer = 0;

uint8_t button_up_state = 0;
uint8_t button_left_state = 0;
uint8_t button_right_state = 0;
uint8_t button_down_state = 0;
uint8_t button_center_state = 0;

#define DAC_PIN 30

/*
screen:
0  = Restart Option
1  = Credits Option
2  = Measure Option
3  = Settings Option
4  = Test Option

9  = Credits
10 = Measurement Mode
12 = Test

Settings screens:
50 = Save / Back to main menu
51 = Backlight On/Off/Auto
52 = LED Brightness
53 = Low HR Warning
54 = High HR Warning
53 = Factory Reset
*/

int screen = 2;
int last_screen = 2;

#define MENU_OPTIONS 5

char *menu_options_text[] = {
	"Restart ",
  "Credits ",
  "Measure ",
  "Settings",
  "Test    "
};

#define CREDITS_SCROLL_TIME 5500000ULL

#define CREDITS_STR "        Created by Peter Kyle for ENGR355 (Embedded Systems Design) at Walla Walla University   Taught by Dr. Natalie Smith-Gray   Winter 2026        "
#define CREDITS_TEXT_LEN (sizeof(CREDITS_STR) - 1)

const char *credits_text = CREDITS_STR;

#define MENU_OPTION_SLIDE_TIME 1500000ULL

signed int menu_option_slide = 0;
// int last_menu_option_slide = 0;
uint64_t menu_option_slide_timer = 0;

#define TEST_MODE_TIME 10000000ULL



// Created with the help of Gemini v3 Pro
void get_slide_frame(int screen, int menu_option_slide, char *output_buffer) {
	  // Create blank 8-character words
    char prev[9] = "        ";
    char curr[9] = "        ";
    char next[9] = "        ";

    // Safely grab the adjacent strings (if they exist)
    if (screen > 0) {
        strncpy(prev, menu_options_text[screen - 1], 8);
				prev[8] = '\0'; // Guarentee null termination
    }
    strncpy(curr, menu_options_text[screen], 8);
		curr[8] = '\0';
    if (screen < MENU_OPTIONS - 1) {
        strncpy(next, menu_options_text[screen + 1], 8);
				next[8] = '\0';
    }

    // Stitch the individual 8 character menu options together into a 24-character "ribbon"
    // Layout: [Prev (0-7)] [Curr (8-15)] [Next (16-23)]
    char ribbon[25] = ""; 
    strcat(ribbon, prev);
    strcat(ribbon, curr);
    strcat(ribbon, next);

    // Calculate the starting index of our 8-character window.
    // Index 8 is the exact start of the 'Current' word.
    // Adding the slide moves the window left (negative) or right (positive).
    int start_index = 8 + menu_option_slide;

    // Copy exactly 8 characters from the calculated starting point
    strncpy(output_buffer, &ribbon[start_index], 8);
    
    // Manually add the null terminator so it's a valid C string
    output_buffer[8] = '\0';
}

// Tt variable is a 64-bit integer but the KL25Z is a 32-bit processor, it takes two clock cycles to read t. If the systick handler first exactly between those two instructions, it will
// corrupt the read, making things think we jumped 4 billion cycles into the future, permanently breaking timers and things. We can fix this by creating the get_safe_time() function.
volatile uint64_t t_unsafe = 3000000; // Time (clock cycles) since boot. Gets incremented by systick. Start it at 3000000 to fast forward past any debounce timers to prevent initial phantom button presses.
uint64_t t = 3000000;

// This ISR triggers every 10000 clock cycles
void SysTick_Handler(void) {
    t_unsafe+=10000; // Increment by 10000 clock cycles
}

uint64_t get_safe_time() {
    __disable_irq();
		__ISB();
    uint64_t safe_t = t_unsafe;
    __enable_irq();
    return safe_t;
}

void delay(volatile uint32_t count) { // Delay Microseconds (approx)
	while(count--) {}
}

void delay_ms(uint32_t n) {
volatile uint32_t i;
volatile uint32_t j;
for(i=0; i < n; i++)
	for(j=0; j < 3500; j++) {}
}

// APA102 Stuff
void spi0_init() {
	SIM->SCGC5 |= SIM_SCGC5_PORTD_MASK; // Enable clock to PORTD
	SIM->SCGC4 |= SIM_SCGC4_SPI0_MASK; // Enable clock to SPI0
	
	// Setup PTD1 and PTD2 to ALT2 (SPI0)
	PORTD->PCR[1] = PORT_PCR_MUX(2); // PTD1 = SPI0_SCK
	PORTD->PCR[2] = PORT_PCR_MUX(2); // PTD2 = SPI0_SOUT
	
	SPI0->C1 = SPI_C1_MSTR_MASK | SPI_C1_SPE_MASK; // MSTR=1 for master mode, spe=1 for spi system enable
	
	SPI0->BR = SPI_BR_SPPR(2) | SPI_BR_SPR(1); // SPPR=2 (divide by 3), SPR=1 (divide by 4)
}

void spi0_write(uint8_t data) {
	// Wait until the Transmit Buffer Empty flag is set
	while(!(SPI0->S & SPI_S_SPTEF_MASK)) {
			// Wait
	}
	// Writing to the Data register clears the flag and transmits
	SPI0->D = data;
}

void apa102_start_frame(void) {
    spi0_write(0x00);
    spi0_write(0x00);
    spi0_write(0x00);
    spi0_write(0x00);
}

void apa102_end_frame(void) {
    spi0_write(0xFF);
    spi0_write(0xFF);
    spi0_write(0xFF);
    spi0_write(0xFF);
}

// Set a single LED color. Brightness is 0-31.
void apa102_send_led(uint8_t r, uint8_t g, uint8_t b, uint8_t brightness) {
    // Ensure brightness is capped at 5 bits (31 max)
    brightness &= 0x1F; 
    
    // The start byte is 0b11100000 (0xE0) OR'd with the 5-bit brightness
    spi0_write(0xE0 | brightness); 
    
    // APA102 expects colors in BGR order
    spi0_write(b);
    spi0_write(g);
    spi0_write(r);
}

uint8_t rgb_leds[6][3] = {{0,0,0},{0,0,0},{0,0,0},{0,0,0},{0,0,0},{0,0,0}}; // Array buffer of LED RGB values
uint8_t rgb_brightness = 31; // 5 bit value

void rgb_refresh() {
	apa102_start_frame();
	for (int i=0; i<6; i++) {
		apa102_send_led(rgb_leds[i][0], rgb_leds[i][1], rgb_leds[i][2], rgb_brightness);
	}
	apa102_end_frame();
}

void rgb_set_led(int led_index, int r, int g, int b) {
	rgb_leds[led_index][0] = r;
	rgb_leds[led_index][1] = g;
	rgb_leds[led_index][2] = b;
}

void rgb_set_leds(int r, int g, int b) {
	for (int i=0; i<6; i++) {
		rgb_leds[i][0] = r;
		rgb_leds[i][1] = g;
		rgb_leds[i][2] = b;
	}
}

// This function was created with the help of Gemini 3 Pro
void set_ring_rainbow_color(int logical_index, uint8_t hue, uint8_t fade_scale) {
    // Map the logical ring position (0-5) to your physical LED indices
    int ring_map[6] = {2, 1, 0, 3, 4, 5};
    int physical_led = ring_map[logical_index];

    uint8_t r, g, b;
    
    // Basic 0-255 color wheel logic
    hue = 255 - hue; 
    if(hue < 85) {
        r = 255 - hue * 3;
        g = 0;
        b = hue * 3;
    } else if(hue < 170) {
        hue -= 85;
        r = 0;
        g = hue * 3;
        b = 255 - hue * 3;
    } else {
        hue -= 170;
        r = hue * 3;
        g = 255 - hue * 3;
        b = 0;
    }
		
		// Scale down to max brightness of ~40, then apply the new fade_scale
    uint32_t r_scaled = (r * 40) / 255;
    uint32_t g_scaled = (g * 40) / 255;
    uint32_t b_scaled = (b * 40) / 255;

    r = (r_scaled * fade_scale) / 255;
    g = (g_scaled * fade_scale) / 255;
    b = (b_scaled * fade_scale) / 255;

    rgb_set_led(physical_led, r, g, b);
}



uint64_t lcd_update_timer = 0;

// Custom LCD Characters
// Heart shape bitmask
uint8_t STARTUP_LOGO[8][8] = {{
	0b01100, // P
	0b10010,
	0b10010,
	0b10010,
	0b11100,
	0b10000,
	0b10000,
	0b00000
},{
	0b10010, // K
	0b10010,
	0b10010,
	0b10100,
	0b11010,
	0b10010,
	0b10010,
	0b00000
},{
	0b00100, // Space half of H
	0b00100,
	0b00100,
	0b00111,
	0b00100,
	0b00100,
	0b00100,
	0b00000
},{
	0b10011, // End of H, half of R
	0b10100,
	0b10100,
	0b10100,
	0b10111,
	0b10101,
	0b10100,
	0b00000
},{
	0b00001, // End of R, Start of M
	0b10001,
	0b10001,
	0b10001,
	0b00001,
	0b00001,
	0b10001,
	0b00000
},{
	0b10110,
	0b01010,
	0b01010,
	0b01010,
	0b01010,
	0b01010,
	0b00010,
	0b00000
},{
	0b01100, // end of M, Half of O
	0b10010,
	0b10010,
	0b10010,
	0b10010,
	0b10010,
	0b01100,
	0b00000
},{
	0b10001,
	0b11001,
	0b11001,
	0b10101,
	0b10011,
	0b10011,
	0b10001,
	0b00000
}
};

uint8_t LEFT_ARROW[8] = {
	0b00000,
	0b00100,
	0b01100,
	0b11111,
	0b01100,
	0b00100,
	0b00000,
	0b00000
};
uint8_t RIGHT_ARROW[8] = {
	0b00000,
	0b00100,
	0b00110,
	0b11111,
	0b00110,
	0b00100,
	0b00000,
	0b00000
};
uint8_t LEFT_ARROW_INV[8] = {
	0b11111,
	0b11011,
	0b10011,
	0b00000,
	0b10011,
	0b11011,
	0b11111,
	0b11111
};
uint8_t RIGHT_ARROW_INV[8] = {
	0b11111,
	0b11011,
	0b11001,
	0b00000,
	0b11001,
	0b11011,
	0b11111,
	0b11111
};

// Pulses the Enable pin to tell the LCD to read the data lines
void LCD_pulse_enable(void) {
	PTC->PSOR = (1 << LCD_EN); // Set EN High
	delay(12);               // 1us delay
	PTC->PCOR = (1 << LCD_EN); // Set EN Low
	delay(50*12);              // Give LCD time to process the data
}

// Writes 4-bit nibble (0b0000 to 0b1111) to PTC0-PTC3
void LCD_write_nibble(uint8_t nibble) {
	// Clear only the bottom 4 bits (PTC0-PTC3)
	PTC->PCOR = 0x0F; 
	
	// Set the bottom 4 bits with our nibble
	PTC->PSOR = (nibble & 0x0F); 
	
	LCD_pulse_enable();
}

void LCD_send_command(uint8_t cmd) {
	PTC->PCOR = (1 << LCD_RS); // RS = 0 for Command
	PTC->PCOR = (1 << LCD_RW); // RW = 0 for Write
	
	LCD_write_nibble(cmd >> 4); // Send high nibble
	LCD_write_nibble(cmd & 0x0F); // Send low nibble
	
	// For commands that need a longer delay, we have to wait a little longer
	if (cmd == 0x01 || cmd == 0x02) {
		delay_ms(5);
	}
}

void LCD_clear() {
	LCD_send_command(0x01);
}

void LCD_home() {
	LCD_send_command(0x02);
}

void LCD_send_data(uint8_t cmd) {
	PTC->PSOR = (1 << LCD_RS); // RS = 1 for Data
	PTC->PCOR = (1 << LCD_RW); // RW = 0 for Write
	
	LCD_write_nibble(cmd >> 4); // Send high nibble
	LCD_write_nibble(cmd & 0x0F); // Send low nibble
}

void LCD_init() {
	// Enable clock to port C
	SIM->SCGC5 |= SIM_SCGC5_PORTC_MASK;
	
	// Configure pins as GPIO
	PORTC->PCR[0]  = PORT_PCR_MUX(1);
	PORTC->PCR[1]  = PORT_PCR_MUX(1);
	PORTC->PCR[2]  = PORT_PCR_MUX(1);
	PORTC->PCR[3]  = PORT_PCR_MUX(1);
	PORTC->PCR[LCD_BL] = PORT_PCR_MUX(1);
	PORTC->PCR[LCD_RS] = PORT_PCR_MUX(1);
	PORTC->PCR[LCD_RW] = PORT_PCR_MUX(1);
	PORTC->PCR[LCD_EN] = PORT_PCR_MUX(1);
	
	// Setup pins to be outputs
	PTC->PDDR |= 0x0F | (1 << LCD_BL) | (1 << LCD_RS) | (1 << LCD_RW) | (1 << LCD_EN);
	
	// Initialize outputs to low
	PTC->PCOR = 0x0F | (1 << LCD_BL) | (1 << LCD_RS) | (1 << LCD_RW) | (1 << LCD_EN);
	PTC->PSOR = (1 << LCD_BL); // Turn on backlight
	
	delay_ms(50);
	
	// Wake up the display
	LCD_write_nibble(0x03);
	delay_ms(5);
	LCD_write_nibble(0x03);
	delay(150*12);
	LCD_write_nibble(0x03);
	delay(50*12);
	
	// Set to 4-bit mode
	LCD_write_nibble(0x02);
	delay(50*12);
	
	LCD_send_command(0x28); // 4-bit mode, 2 lines, 5x8 font
	LCD_send_command(0x08); // Display off
	LCD_send_command(0x01); // Clear display
	LCD_send_command(0x06); // Entry mode: increment cursor, no shift
	LCD_send_command(0x0C); // Display On, no cursor, no blinking
}

void LCD_send_int(int value) { // Send a single decimal digit
	LCD_send_data(value+48);
}

void LCD_send_single_hex(uint32_t value) {
	if (value < 10) {
		LCD_send_data(value+48);
	} else {
		LCD_send_data(value-10+65);
	}
}

void LCD_send_hex(uint16_t value) {
	for (int i=0; i<4; i++) {
		LCD_send_single_hex((value >> (4*(3-i))) & 0xF);
	}
}

// This recursive function was created with the assistance of Gemini v3.
void LCD_send_number(int n) {
	if (n<0) { // Handle negative numbers if necessary
		n = -n;
	}
	if (n/10 > 0) {
		LCD_send_number(n / 10);
	}
	LCD_send_data(n%10 + '0');
}

void LCD_send_string(char string[]) {
	//LCD_clear();
	//LCD_home();
	int length = strlen(string);
	for (int i=0; i<length; i++) {
		if (string[i] == '\n') {
			LCD_send_command(0xC0);
		} else {
			LCD_send_data(string[i]);
		}
	}
}

void LCD_create_char(uint8_t location, uint8_t charmap[]) { // Lcation is 0-7 slot to save character in. Charmap is an array of 8 bytes for the pixel grid
    location &= 0x07; // Constrain location to 0-7
    
    // Command 0x40 sets the CGRAM address. 
    // We multiply location by 8 (shift left 3) because each char is 8 bytes.
    LCD_send_command(0x40 | (location << 3)); 
    
    // Send the 8 bytes of the character
    for (int i = 0; i < 8; i++) {
        LCD_send_data(charmap[i]);
    }
}

void LCD_set_cursor(uint8_t col, uint8_t row) {
    uint8_t address;
    if (row == 0) {
        address = col;          // Top row starts at 0x00
    } else {
        address = 0x40 + col;   // Bottom row starts at 0x40
    }

    LCD_send_command(0x80 | address);
}

void PWM_init(void) { // Initialize PWM for LEDs on PTC8, and PTC9. Unfortunately, PTC10 (Green LED) does not support PWM from the TPM.
    
    // Set PTC8 and PTC9 to Alt3 (TPM0_CH4 and TPM0_CH5)
    PORTC->PCR[8] = PORT_PCR_MUX(3);
    PORTC->PCR[9] = PORT_PCR_MUX(3);
    
    // Select the clock source for the TPM modules
    SIM->SOPT2 |= SIM_SOPT2_TPMSRC(1); 
    
    SIM->SCGC6 |= SIM_SCGC6_TPM0_MASK; // Enable clock to the TPM0 module (PTC8 and PTC9 use TPM0, not TPM2)
    
    TPM0->SC = 0; // Disable TPM0 counter while we configure it
    
    TPM0->MOD = 48000; // Set the Modulo (MOD) register for your frequency
    
    // Configure TPM0 Channel 4 (PTC8) and Channel 5 (PTC9) for Edge-Aligned PWM
    TPM0->CONTROLS[4].CnSC = TPM_CnSC_MSB_MASK | TPM_CnSC_ELSB_MASK;
    TPM0->CONTROLS[5].CnSC = TPM_CnSC_MSB_MASK | TPM_CnSC_ELSB_MASK;
    
    // Set initial duty cycle to 0 (off)
    TPM0->CONTROLS[4].CnV = 0; 
    TPM0->CONTROLS[5].CnV = 0; 
    
    // Start the timer counter
    TPM0->SC |= TPM_SC_CMOD(1);
}

void LED_init() {
	PWM_init();
	PORTC->PCR[10] = PORT_PCR_MUX(1); // Setup green led (PTC10) as GPIO
	PTC->PDDR |= (1 << 10); // Setup green led (PTC10) as output
	PTC->PCOR = (1 << 10); // Turn off green led
}

void red_led(uint8_t brightness) {
	// Change brightness of the red LED on PTC8 (Channel 4)
	TPM0->CONTROLS[4].CnV = brightness*48000/255; // 50% duty cycle
}

void yellow_led(uint8_t brightness) {
	// Change brightness of the red LED on PTC8 (Channel 4)
	TPM0->CONTROLS[5].CnV = brightness*48000/255; // 50% duty cycle
}

void green_led(int state) {
	if (state) {
		PTC->PSOR = (1 << 10); // Turn on green led
	} else {
		PTC->PCOR = (1 << 10); // Turn off green led
	}
}

void buttons_init() {
	// Configuration for button pins
	// MUX(1)    = GPIO
	// PE_MASK   = Enable internal pull resistor
	// PS_MASK   = Set pull resistor to Pull-Up (High)
	// IRQC(10)  = Trigger interrupt on Falling Edge (High-to-Low transition)
	uint32_t pcr_setup = PORT_PCR_MUX(1) | PORT_PCR_PE_MASK | PORT_PCR_PS_MASK;
	
	// Apply that configuration to the button pins
	PORTA->PCR[BUTTON_UP]  = pcr_setup;
	PORTA->PCR[BUTTON_LEFT] = pcr_setup;
	PORTA->PCR[BUTTON_RIGHT] = pcr_setup;
	PORTA->PCR[BUTTON_DOWN] = pcr_setup;
	PORTA->PCR[BUTTON_CENTER] = pcr_setup;
	
	// Set button pins as inputs by clearing them to zero
	PTA->PDDR &= ~(MASK(BUTTON_UP) | MASK(BUTTON_LEFT) | MASK(BUTTON_RIGHT) | MASK(BUTTON_DOWN) | MASK(BUTTON_CENTER));
}

void button_up_rising_handler() {
	green_led(1);
}
void button_up_falling_handler() {
	green_led(0);
}
void button_left_rising_handler() {
	if (screen > 0 && screen <= 4) {
		LCD_set_cursor(1, 1);
		LCD_send_data(2);
		if (menu_option_slide == 0) {
			screen--;
			menu_option_slide = 8;
		}
		LCD_set_cursor(6, 1);
		LCD_send_data(1);
	} else if (screen != 12) {
		LCD_set_cursor(1, 1);
		LCD_send_data(' ');
	}
}
void button_left_falling_handler() {
	if (screen > 0 && screen <= 4) {
		LCD_set_cursor(1, 1);
		LCD_send_data(0);
	} else if (screen != 12) {
		LCD_set_cursor(1, 1);
		LCD_send_data(' ');
	}
}
void button_right_rising_handler() {
	if (screen < 4) {
		LCD_set_cursor(6, 1);
		LCD_send_data(3);
		if (menu_option_slide == 0) {
			screen++;
			menu_option_slide = -8;
		}
		LCD_set_cursor(1, 1);
		LCD_send_data(0);
	} else if (screen != 12) {
		LCD_set_cursor(6, 1);
		LCD_send_data(' ');
	}
}
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
int main(void) {
	// Enable clocks
	SIM->SCGC5 |= SIM_SCGC5_PORTA_MASK;
	SIM->SCGC5 |= SIM_SCGC5_PORTB_MASK;
	SIM->SCGC5 |= SIM_SCGC5_PORTC_MASK;
	SIM->SCGC5 |= SIM_SCGC5_PORTD_MASK;
	
	SysTick_Config(10000); // Increment the counter every 10000 clock cycles

	
	LCD_init(); // initialize LCD display
	LED_init();
	buttons_init();
	
	init_adc();
	init_dac();
	
	spi0_init(); // Initiallize SPI for APA102 leds
	
	for (int i=0; i<8; i++) {
		LCD_create_char(i, STARTUP_LOGO[i]);
	}
	
	rgb_set_leds(0,0,0);
	rgb_refresh();
	
	
	
	LCD_home();
	for (int i=0; i<8; i++) {
		LCD_send_data(i); // Display the startup logo on the first 8 characters
	}
	LCD_set_cursor(0, 1);
	LCD_send_string("Starting");
	
	for (int i=0; i<=280; i++) {
		if (i <= 80) {
			red_led(i);
			rgb_set_led(0,i*2,0,0);
			rgb_set_led(3,i*2,0,0);
		} else if (i <= 160) {
			red_led(160-i);
			rgb_set_led(0,(160-i)*2,0,0);
			rgb_set_led(3,(160-i)*2,0,0);
		}
		if (i >= 60 && i <= 140) {
			yellow_led((i-60)*2);
			rgb_set_led(1,(i-60),(i-60)*0.3,0);
			rgb_set_led(4,(i-60),(i-60)*0.3,0);
		} else if (i >= 140 && i <= 220) {
			yellow_led((220-i)*2);
			rgb_set_led(1,(220-i),(220-i)*0.3,0);
			rgb_set_led(4,(220-i),(220-i)*0.3,0);
		}
		if (i >= 120 && i <= 200) {
			rgb_set_led(2,0,(i-120),0);
			rgb_set_led(5,0,(i-120),0);
		} else if (i >= 200 && i <= 280) {
			rgb_set_led(2,0,(280-i),0);
			rgb_set_led(5,0,(280-i),0);
		}
		if (i == 120) {
			green_led(1);
		}
		if (i == 280) {
			green_led(0);
		}
		rgb_refresh();
		delay_ms(5);
	}
	
	// Load left and right arrow custom characters
	LCD_create_char(0, LEFT_ARROW);
	LCD_create_char(1, RIGHT_ARROW);
	LCD_create_char(2, LEFT_ARROW_INV);
	LCD_create_char(3, RIGHT_ARROW_INV);
	
	LCD_clear();
	LCD_send_string("Measure");
	LCD_set_cursor(1, 1);
	LCD_send_data(0);
	LCD_set_cursor(6, 1);
	LCD_send_data(1);
	
	char lcd_render_buffer[9];
	
	while (1) {
		t = get_safe_time();
		button_task();
		
		if (screen < 5) { // We're selecting a menu option
			if (last_screen == 10) { // If we're coming from the measure mode, we need to make sure the yellow led is off.
				yellow_led(0);
				rgb_set_leds(0, 0, 0);
				rgb_refresh();
			}
			if (last_screen == 12) { // If we're coming from test mode, all the LCD characters will be blocks and we'll need to clear the LCD
				LCD_clear();
				red_led(0);
				yellow_led(0);
				green_led(0);
			}
			if (menu_option_slide != 0) { // If a slide has been triggered (the slide variable is not zero and is somewhere between -8 and 8)
				if (t - menu_option_slide_timer >= MENU_OPTION_SLIDE_TIME ) { // If it's time to slide
					menu_option_slide_timer = t;
					if (menu_option_slide < 0) { // Need to increment slide
						menu_option_slide++;
					} else { // Need to decrement slide
						menu_option_slide--;
					}
					get_slide_frame(screen, menu_option_slide, lcd_render_buffer); // Get the 8-character window of the menu options
					//LCD_clear();
					LCD_set_cursor(0, 0);
					LCD_send_string(lcd_render_buffer);
				}
			} else if (screen != last_screen) {
				yellow_led(0);
				rgb_set_leds(0, 0, 0);
				rgb_refresh();
				last_screen = screen;
				if (screen <= 4) {
					//LCD_clear();
					LCD_set_cursor(0, 0);
					LCD_send_string(menu_options_text[screen]);
					if (screen != 4) {
						LCD_set_cursor(6, 1);
						LCD_send_data(1);
					} else {
						LCD_set_cursor(6, 1);
						LCD_send_data(' ');
					}
					if (screen != 0) {
						LCD_set_cursor(1, 1);
						LCD_send_data(0);
					} else {
						LCD_set_cursor(1, 1);
						LCD_send_data(' ');
					}
				}
			}
		} else { // We're not selecting a menu option
			if (screen == 9) { // We're in credits mode
				if (screen != last_screen) { // Just got to this screen
					last_screen = screen;
					credits_scroll_index = 0;
					LCD_clear();
					LCD_set_cursor(0, 0);
					strncpy(credits_scroll_text, credits_text, 8); // Copy the first 8 characters from credits_text to the credits_scroll_text buffer
					LCD_send_string(credits_scroll_text); // Set to the first 8 characters of credits
					credits_scroll_timer = t;
					
					// Reset fade timer when entering the menu
          credits_start_time = t;
				}
				if (t-credits_scroll_timer > CREDITS_SCROLL_TIME) { // Time for a scroll update!
					credits_scroll_timer = t;
					credits_scroll_index++;
					if (credits_scroll_index > CREDITS_TEXT_LEN) {
						credits_scroll_index = 0;
					}
					LCD_set_cursor(0, 0);
					strncpy(credits_scroll_text, credits_text+credits_scroll_index, 8); // Copy the first 8 characters from credits_text to the credits_scroll_text buffer
					LCD_send_string(credits_scroll_text); // Set to the first 8 characters of credits
				}
				
				// RGB LED rainbow stuff created with the help of Gemini 3 Pro
				if (t - credits_rainbow_timer > 500000) { 
					credits_rainbow_timer = t;
					credits_rainbow_hue++; 
					
					uint64_t elapsed_fade = t - credits_start_time;

					for (int i = 0; i < 6; i++) {
						uint8_t pixel_hue = credits_rainbow_hue + (i * 42);
						
						// Map to physical LED to determine the pair (0/3, 1/4, 2/5)
						int ring_map[6] = {2, 1, 0, 3, 4, 5};
						int physical_led = ring_map[i];
						int pair_index = physical_led % 3; // cleanly groups them into 0, 1, and 2

						// Calculate fade scaling for this specific pair
						uint64_t pair_start_time = pair_index * CREDITS_FADE_STAGGER_CYCLES;
						uint8_t fade_scale = 0;

						if (elapsed_fade >= pair_start_time) {
							uint64_t time_fading = elapsed_fade - pair_start_time;
							if (time_fading >= CREDITS_FADE_TIME_CYCLES) {
									fade_scale = 255; // Fully faded in
							} else {
									fade_scale = (time_fading * 255) / CREDITS_FADE_TIME_CYCLES;
							}
						}
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

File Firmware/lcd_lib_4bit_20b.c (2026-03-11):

/*----------------------------------------------------------------------------*/
/*  LCD initialization and data transfer routines                             */
/*       4-bit bus version                                                    */
/*  Filename: lcd_lib_4bit_20b.c                                              */
/*  Author:   Larry Aamodt                                                    */
/*  Version:  1/25/19 written                                                 */
/*            1/28/19 updated                                                 */
/*            1/29/20 updated for wtr 2020 project                            */
/*            2/12/20 revised LCD control signal port & pins                  */
/*            3/10/21 added defines for cursor commands                       */
/*            1/19/22 updated comments re clock turn on. No code changes      */
/*            1/21/26 Peter Kyle - added static redefinitions of ptb, ptc     */
/*  Compiler: Keil uVision5                                                   */
/*  Hardware: NXP Freedom board & a 2x8 or 2x16 LCD display w/parallel interfc*/
/*            PORT B  bits 1,2,3 used for control                             */
/*            PORT C  bits 0,1,2,3 used for data                              */
/*  Software note:  A software loop is used for time delay generation         */
/*        Port B and C clocks must be turned on before calling these routines */
/*  Function use:   call LCD_command to move the cursor, clear screen, etc.   */
/*                  call LCD_send_data to send one ASCII character code       */
/*----------------------------------------------------------------------------*/
#include <stdint.h>
#include <MKL25Z4.h>

#define MASK(x) (1UL << (x))

#define LCD_EN              0x00020000    // PTC17 LCD enable 
#define LCD_RW              0x00010000    // PTC16 LCD read/write
#define LCD_RS              0x00002000    // PTC13 LCD RS
#define LCD_LOW4_MASK       0x0000000F    // low 4 bits of a command
#define LCD_UPPER4_MASK     0x000000F0    // upper 4 bits of a command
#define LCD_MASK            0x0000000F    // PortC bits 0-3
#define LCD_DATA_PINS       0x0000000F    // PortC LCD data pins
#define LCD_CNTRL_PINS      (LCD_EN | LCD_RW | LCD_RS)    // PortC LCD control pins

#define clear_screen 0x01
#define cursor_left 0x10
#define cursor_right 0x14
#define cursor_line1 0x80
#define cursor_line2 0xC0


/*----------------------------------------------------------------------------
  LCD functions 
 *----------------------------------------------------------------------------*/
void LCD_command(uint32_t command);       // use to send LCD commands
void LCD_send_data(uint32_t data);        // use to send one char to screen
void delayMs(uint32_t n);
void pulse_the_LCD_enable(void);
void LCD_init(void);

/*----------------------------------------------------------------------------
  Initialize the LCD in 4-bit bus mode.         L.Aamodt
 *----------------------------------------------------------------------------*/
void LCD_init(void)
{
  // Note: you need to turn on Port B and C clocks prior to calling this routine

	uint32_t k;

     // First set up bits in GPIO Port C used by the LCD
	for (k=0; k<4; k++) {                  // make ports GPIO
	PORTC->PCR[k] &= ~PORT_PCR_MUX_MASK;    // 4 LCD data bits
	PORTC->PCR[k] |= PORT_PCR_MUX(1);
	}
	
	// Set up bits in GPIO Port C used by the LCD control pins
	PORTC->PCR[13] &= ~PORT_PCR_MUX_MASK;
	PORTC->PCR[13] |= PORT_PCR_MUX(1);
	
	PORTC->PCR[16] &= ~PORT_PCR_MUX_MASK;
	PORTC->PCR[16] |= PORT_PCR_MUX(1);
	
	PORTC->PCR[17] &= ~PORT_PCR_MUX_MASK;
	PORTC->PCR[17] |= PORT_PCR_MUX(1);
	
	// Set all data and control pins to output
  PTC->PDDR |= (LCD_DATA_PINS | LCD_CNTRL_PINS);

	PTC->PCOR = LCD_RW | LCD_RS | LCD_EN;   // clear R/W, RS, and EN	
	
	// Now initialize the LCD itself
	delayMs(00);
	PTC->PCOR = LCD_MASK;                   // clear output data bits to 0
	PTC->PSOR = (0x3);                   // put a wake-up value on bus
	delayMs(10);
	pulse_the_LCD_enable();
	delayMs(1);
	pulse_the_LCD_enable();
	delayMs(1);
	pulse_the_LCD_enable();
	delayMs(1);
	PTC->PCOR = LCD_MASK;                   // clear output data bits to 0
	PTC->PSOR = (0x2);                   // initialize to 4-bit bus mode
	delayMs(10);
	pulse_the_LCD_enable();
	LCD_command(0x28);                      // Set to 4-bit/2-line/5x7pixels
	LCD_command(0x10);                      // 
	LCD_command(0x0F);                      // Display on, cursor on and blink
	LCD_command(0x06);                      //
}
/*----------------------------------------------------------------------------
  Send a command to the LCD                      L.Aamodt
 *----------------------------------------------------------------------------*/
void LCD_command(uint32_t command)
{
	PTC->PCOR = LCD_RW | LCD_RS | LCD_EN;   // clear R/W, RS, and EN
	PTC->PCOR = LCD_MASK;                   // clear output data bits to 0
	PTC->PSOR = (command & LCD_UPPER4_MASK)>>4; // output upper 4 bits of command
	pulse_the_LCD_enable();
	PTC->PCOR = LCD_MASK;                   // clear output data bits
	PTC->PSOR = (command & LCD_LOW4_MASK);   // output lower 4 bits
	pulse_the_LCD_enable();
	if (command < 4)
		delayMs(3);                           // command 1 and 2 need 1.64ms
	else
		delayMs(1);                           // all others 40us
}
/*----------------------------------------------------------------------------
   Pulse the LCD enable line                    L.Aamodt
 *----------------------------------------------------------------------------*/
void pulse_the_LCD_enable(void)
{
	PTC->PSOR = LCD_EN;                     // assert enable
	delayMs(1);
	PTC->PCOR = LCD_EN;                     // de-assert enable
}

/*----------------------------------------------------------------------------
   Send data (one character, using ASCII code) to the LCD      L.Aamodt
 *----------------------------------------------------------------------------*/
void LCD_send_data(uint32_t data)
{
	
	PTC->PCOR = LCD_RW | LCD_EN;            // clear R/W, RS, and EN
	PTC->PSOR = LCD_RS;                     // set RS high
	PTC->PCOR = LCD_MASK;                   // clear output data bits to 0
	PTC->PSOR = (data & LCD_UPPER4_MASK)>>4;   // output upper 4 bits of command
	pulse_the_LCD_enable();
	PTC->PCOR = LCD_MASK;                   // clear output data bits
	PTC->PSOR = (data & LCD_LOW4_MASK);  // output lower 4 bits
	pulse_the_LCD_enable();
}
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

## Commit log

2026-03-08 Fully functioning BPM measurement and LED effects added
    Other than the measurement, menu options have no functionality yet.
2026-03-08 Fixed LCD Bug in Measurement Mode
    When the LCD prints a 3 digit number, then goes back to -- because the pulse period was too long, it didn't lead with a space, so the first digit of the 3 digit number was left. This has been fixed now.
    [main.c]
2026-03-09 Finished Implementing Credits and Reset
    Also fixed 2025 to 2026 in the credits_text
    [main.c]
2026-03-11 Changed LCD backlight resistance to 0
    [main (66 unrouted).kicad_pcb, main (halfway routed).kicad_pcb, main.kicad_sch]
2026-03-15 Fixed Test Page LEDs and Reset
    [main.c]
2026-03-15 Added 3 standard LEDs to the test mode
